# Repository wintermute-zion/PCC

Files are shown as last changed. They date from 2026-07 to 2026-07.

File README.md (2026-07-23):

# PCC (Physical Control Center)

PCC is a macropad with six keys and a rotary encoder. I designed it to control things like my PC's volume and media playback (hence the "Physical Control Center" name) but you can build a new firmware to map the keys to do anything, really.

Designed for Hack Club's Hackpad program. (view it [here](https://hackpad.hackclub.com))

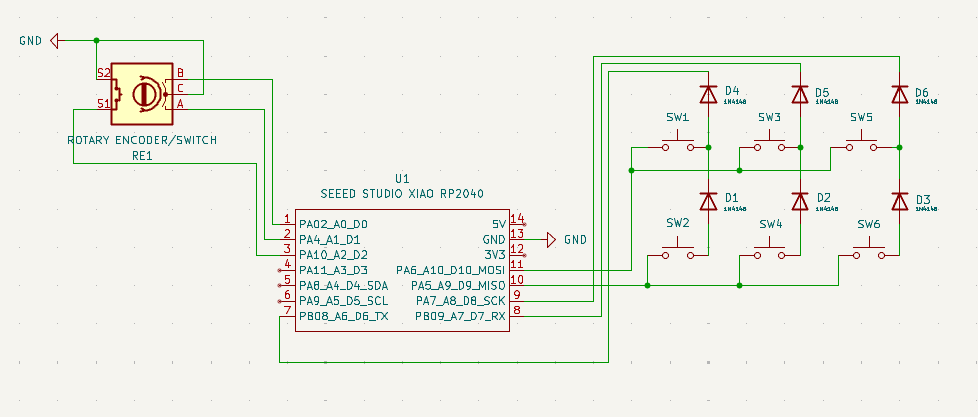
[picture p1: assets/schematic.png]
Screenshot of KiCad schematic of PCC's wiring connections

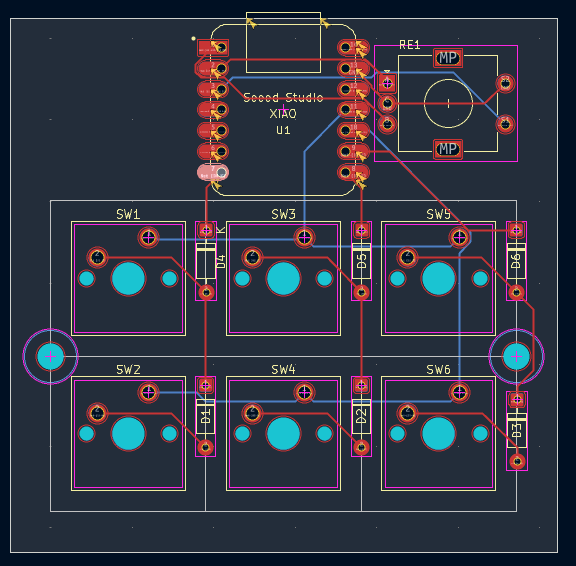
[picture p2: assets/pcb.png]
Screenshot of PCC's PCB design in KiCad


## Disclaimer!

I haven't recieved my PCB or kit from Hack Club as of yet, so both the case and firmware code are not guaranteed to work with this macropad on the first try (the case may not fit, the firmware may reference a key that doesn't exist, I don't know). Obviously once I recieve everthing I will fix any problems that should arise, but until then, continue cautiously.

## Case

The case is in two parts, held together with screws driven through holes in the top case's corners. All screws in the case screw into heat-set inserts, so to allow easier disassembly, if that's something you'll need.

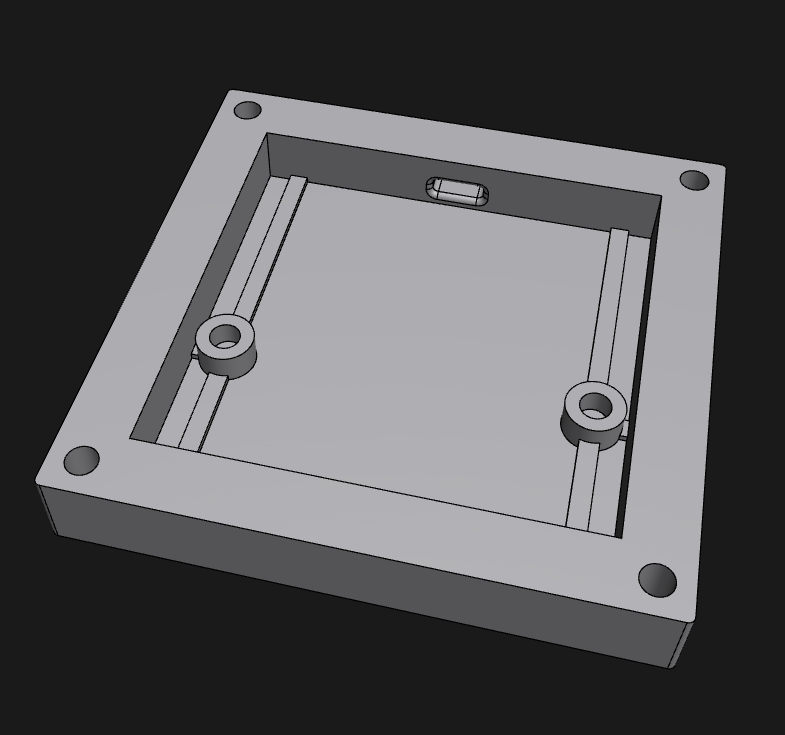
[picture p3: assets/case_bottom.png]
Screenshot of 3D model of bottom half of PCC's case in Shapr3D

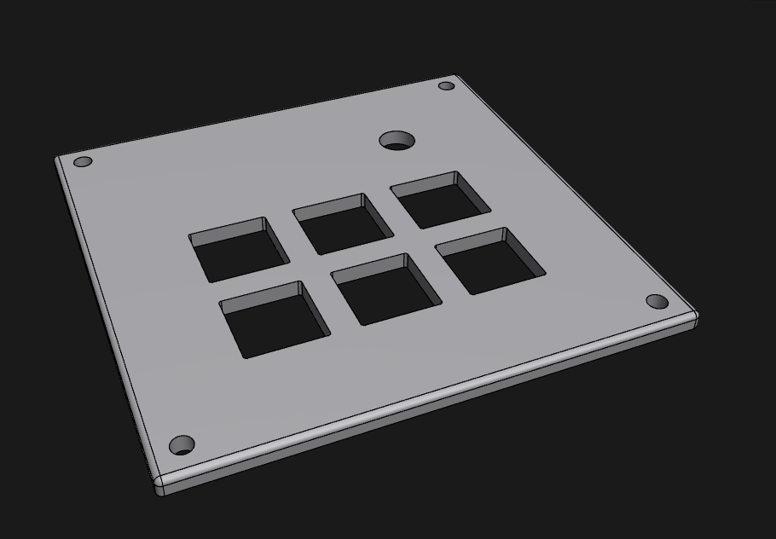
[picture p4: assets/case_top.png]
Screenshot of 3D model of top hald of PCC's case in Shapr3D


## Firmware

KMK firmware is used for this macropad, though I'm sure you could make a QMK version if you so please. I chose KMK since it uses Python though. View the firmware code [here.](https://github.com/wintermute-zion/PCC/blob/main/production/main.py)

## Pinouts

### Key Matrix

| Row/Column | Digital GPIO Pin | GPIO Pin |
| --- | --- | --- |
| Row 1 | D10 | GPIO3 |
| Row 2 | D9 | GPIO4 |
| Column 1 | D6 | GPIO0 |
| Column 2 | D7 | GPIO1 |
| Column 3 | D8 | GPIO2 |

### Rotary Encoder

| Pin | Digital GPIO Pin | GPIO Pin |
| --- | --- | --- |
| A | D1 | GPIO27 |
| B | D0 | GPIO26 |
| S1  | D2 | GPIO28 |

## Key Map

### Key Matrix

| | Column 1 | Column 2 | Column 3 |
| ----- | --- | --- | --- |
| Row 1 | Play/Pause Media | Stop Track (Win) | Show Desktop (Win) |
| Row 2 | Previous Track (Win) | Next Track (Win) | Lock PC (Win) |

### Rotrary Encoder

| | |
| --- | --- |
| Knob turn left | Volume Down |
| Knob turn right  | Volume Up |
| Knob button push | Audio Mute  |

## BOM

A list of everything you'd need to build this. You can view this as a .csv file [here.](https://github.com/wintermute-zion/PCC/blob/main/BOM%20.csv)

- (1) Seeed Studio XIAO RP2040 MCU
- (6) Cherry MX keyboard switches
- (1) EC11 rotary encoder
- (6) 1N4148 diodes
- (6) M3 x 5mm x 4mm heatset inserts
- (6) M3 x 16mm screws
- (6) Keycaps
- (1) Custom PCB
- (1) Case bottom
- (1) Case top

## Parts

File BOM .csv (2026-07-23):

Item | Quantity | Custom Part Link
Seeed Studio XIAO RP2040 MCU | 1
Cherry MX keyboard switches | 6
EC11 rotary encoder | 1
1N4148 diodes | 6
M3 x 5mm x 4mm heatset inserts | 6
M3 x 16mm screws | 6
Keycaps | 6
Custom PCB | 1 | https://github.com/wintermute-zion/PCC/blob/main/production/gerbers.zip
Case bottom | 1 | https://github.com/wintermute-zion/PCC/blob/main/production/case_bottom.stl
Case top | 1 | https://github.com/wintermute-zion/PCC/blob/main/production/case_top.stl

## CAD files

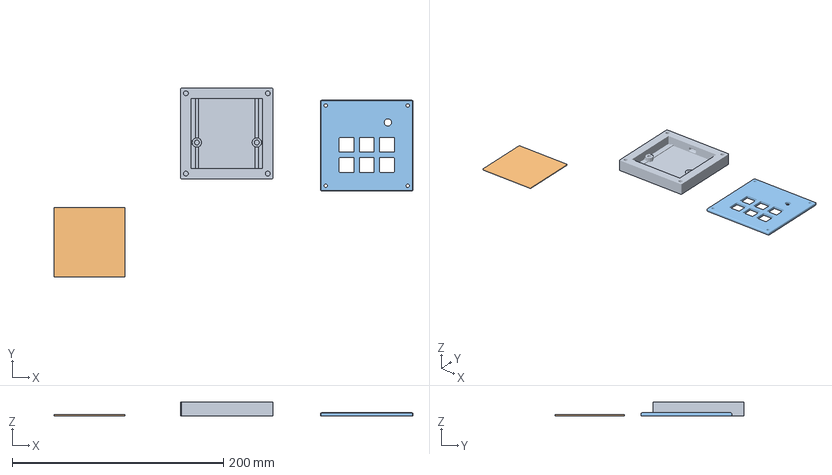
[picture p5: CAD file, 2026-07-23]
cad/pcc_v1.3mf
339.7 x 178.7 x 13.0 mm

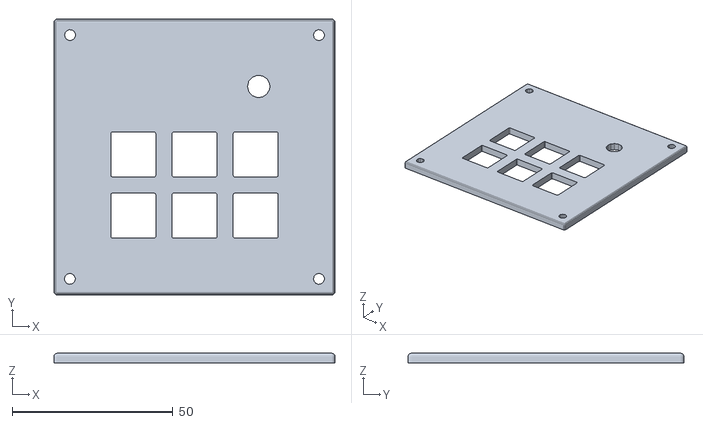
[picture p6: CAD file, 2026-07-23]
production/case_top.stl
87.5 x 85.9 x 3.00

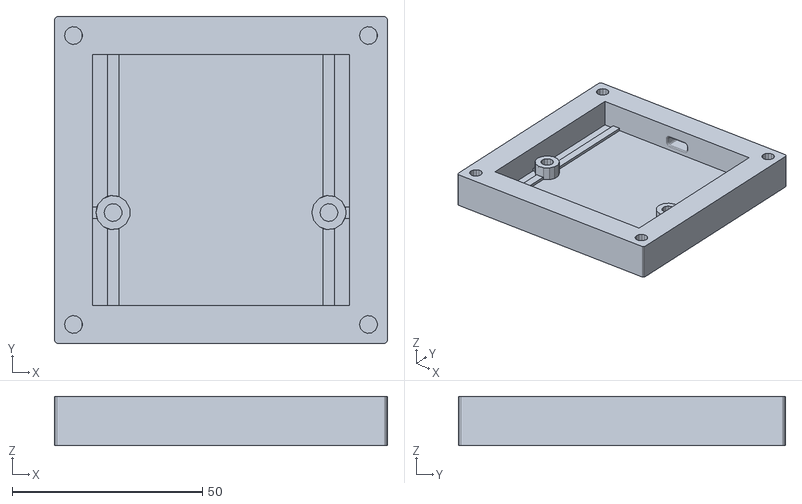
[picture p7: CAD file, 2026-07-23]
production/case_bottom.stl
87.5 x 85.9 x 13.0

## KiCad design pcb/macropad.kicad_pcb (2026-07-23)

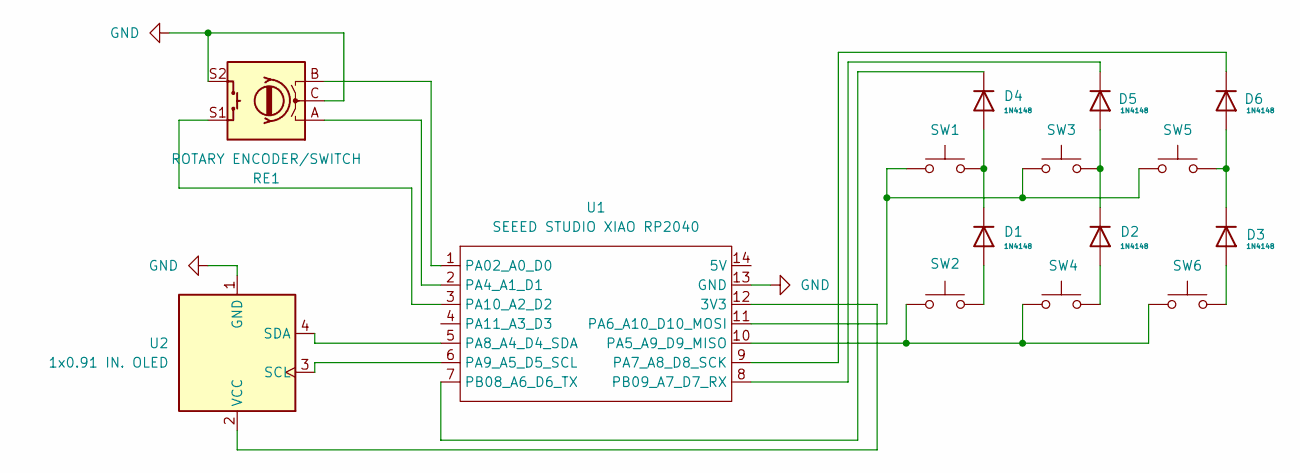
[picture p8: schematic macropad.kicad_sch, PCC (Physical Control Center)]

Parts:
D1, D2, D3, D4, D5, D6: 1N4148; D_DO-35_SOD27_P7.62mm_Horizontal
RE1: ROTARY ENCODER/SWITCH; RotaryEncoder_Alps_EC11E-Switch_Vertical_H20mm
SW1, SW2, SW3, SW4, SW5, SW6: SW_Push; SW_Cherry_MX_1.00u_PCB
U1: SEEED STUDIO XIAO RP2040; XIAO-Generic-Hybrid-14P-2.54-21X17.8MM
U2: 1x0.91 IN. OLED; ER_OLEDM0.91_1x-I2C

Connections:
GND: RE1.C, RE1.S2, U1.13 (GND), U2.1 (GND)
unnamed: D1.2 (A), SW2.2
unnamed: D1.1 (K), D4.2 (A), SW1.2
unnamed: D2.2 (A), SW4.2
unnamed: D2.1 (K), D5.2 (A), SW3.2
unnamed: D3.2 (A), SW6.2
unnamed: D3.1 (K), D6.2 (A), SW5.2
unnamed: D4.1 (K), U1.7 (PB08_A6_D6_TX)
unnamed: D5.1 (K), U1.8 (PB09_A7_D7_RX)
unnamed: D6.1 (K), U1.9 (PA7_A8_D8_SCK)
unnamed: U1.12 (3V3), U2.2 (VCC)
unnamed: RE1.B, U1.1 (PA02_A0_D0)
unnamed: RE1.A, U1.2 (PA4_A1_D1)
unnamed: SW2.1, SW4.1, SW6.1, U1.10 (PA5_A9_D9_MISO)
unnamed: SW1.1, SW3.1, SW5.1, U1.11 (PA6_A10_D10_MOSI)
unnamed: U1.5 (PA8_A4_D4_SDA), U2.4 (SDA)
unnamed: U1.6 (PA9_A5_D5_SCL), U2.3 (SCL)
unnamed: RE1.S1, U1.3 (PA10_A2_D2)

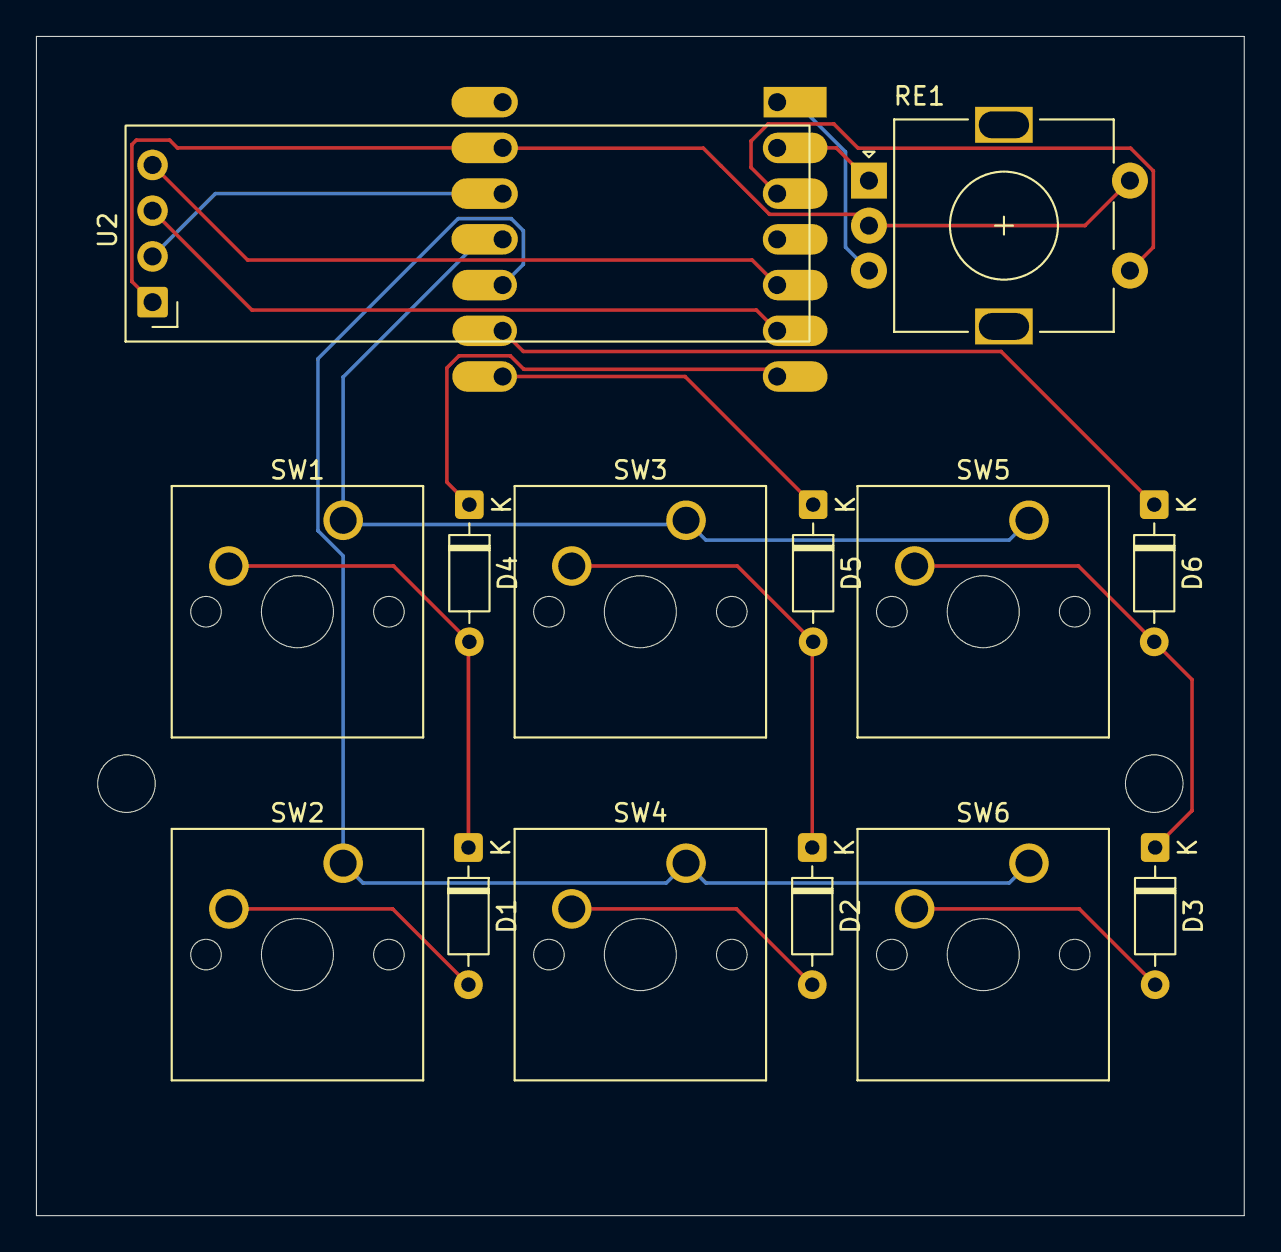
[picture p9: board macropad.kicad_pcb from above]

Board: 2 copper layers, 67.1 x 65.5 mm, 15 parts (1 on the bottom side), 18 nets.

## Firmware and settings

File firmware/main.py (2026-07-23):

import board

#import extensions/modules
from kmk.kmk_keyboard import KMKKeyboard
from kmk.keys import KC
from kmk.scanners import DiodeOrientation
from kmk.extensions.media_keys import MediaKeys
from kmk.modules.encoder import EncoderHandler

encoder_handler = EncoderHandler()
keyboard.modules = [encoder_handler]
keyboard.extensions.append(MediaKeys())
keyboard = KMKKeyboard()

#specify encoder GPIO pins
encoder_handler.pins = ((board.GP27, board.GP26, board.GP28))

#specify key matrix GPIO pins and diode orientation
keyboard.col_pins = (board.GP0, board.GP1, board.GP2)
keyboard.row_pins = (board.GP3, board.GP4)
keyboard.diode_orientation = DiodeOrientation.ROW2COL

#keypad key mapping
keyboard.keymap = [
    [KC.MEDIA_PLAY_PAUSE, KC.MEDIA_STOP, KC.LGUI(KC.D),
     KC.MEDIA_PREV_TRACK, KC.MEDIA_NEXT_TRACK, KC.LGUI(KC.L)
    ]
]

#encoder key mapping
encoder_handler.map = [((KC.AUDIO_VOL_UP, KC.AUDIO_VOL_DOWN, KC.AUDIO_MUTE))]

if __name__ == '__main__':
    keyboard.go()

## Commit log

2026-07-18 Initialize repository
    [macropad.kicad_pcb, macropad.kicad_sch, pcc_case.3mf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]
2026-07-23 Update README.md
    Fix wrong file path to schematic image in README.md
2026-07-23 Remove mentions of display
    Remove mentions of display after removal from PCB
2026-07-23 Update images without display
    [case_bottom.stl, case_top.stl, macropad.kicad_pcb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]
2026-07-23 Prepare files to ship
    [case_top.stl, pcc_case.3mf, pcc_v1.3mf]
2026-07-23 Create BOM.csv and link to README.md
    Create a .csv file with a BOM, then link it to README.md
    [BOM .csv]
2026-07-23 Update BOM link in README.md
